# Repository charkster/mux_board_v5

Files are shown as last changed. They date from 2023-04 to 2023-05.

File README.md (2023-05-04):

# mux_board_v5
Custom PCB with SAMD21 QT PY controlling TWO ADG1606BRUZ 16 input muxes! This board is 30% smaller than V3 and uses a single 16x2 pin header. There are two firmwares for this board, as the backside input pin numbering does not match the topside numbering. You can select which side you would like to be on-top... the QT PY board is much taller than the ADG1606BRUZ packages, and I plan to have the backside on-top (to aviod any unwanted contact with the boards that I connect to).

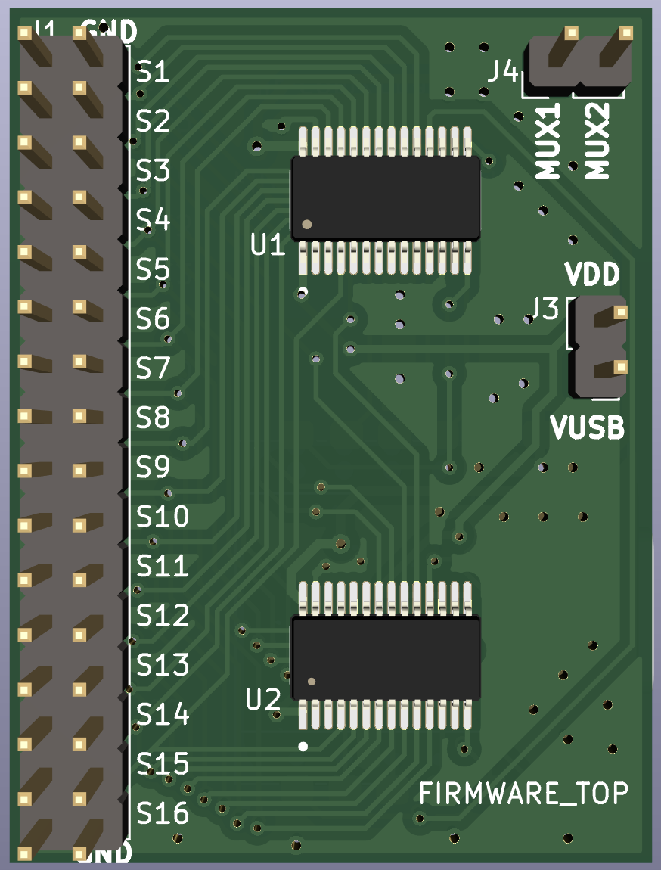
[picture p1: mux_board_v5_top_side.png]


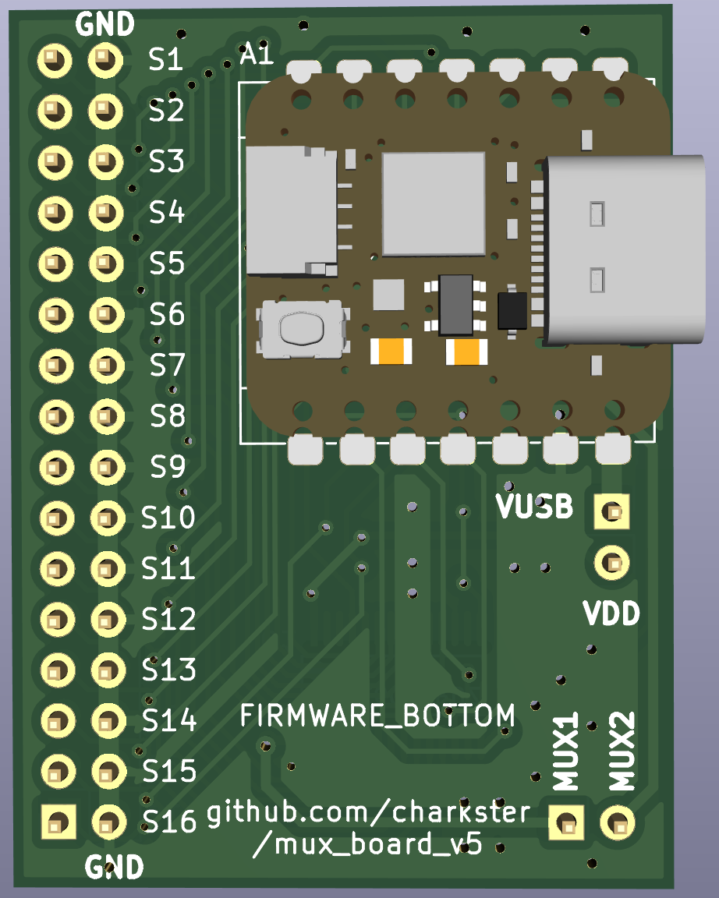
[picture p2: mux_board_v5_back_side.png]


Check-out my **PDF** [schematic](https://github.com/charkster/mux_board_v5/blob/main/mux_board_v5.pdf) !!

The SAMD21 QT PY can be programmed with the appropriate file (drag-n-drop) from the uf2_firmware folder. 

**Supported USBTMC commands:**

**MUX1:EN 1** # enable MUX1, a zero will disable the mux

**MUX1:SEL 1** # select S1 input, values 1 through 16 are valid

**MUX1:EN?** # this query returns the state of MUX1

**MUX1:SEL?** # this query returns the presently selected input

***RST** # disables all MUX enables

***IDN?** # returns valid commands and this URL

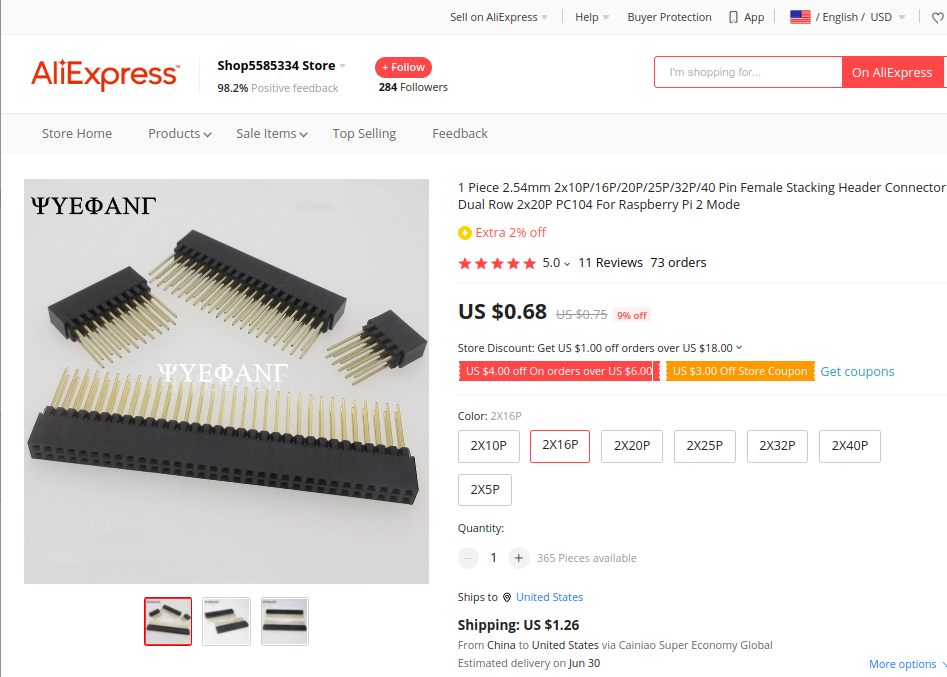
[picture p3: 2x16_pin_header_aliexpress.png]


2x16 2.54mm stacking headers can be found on [Aliexpress](https://www.aliexpress.us/item/2255800630914427.html)



SAMD21 QT PY and ADG1606BRUZ ICs can be found on Digikey/Mouser.

The tinyusb_usbtmc_src files are modifications of https://github.com/hathach/tinyusb source files.

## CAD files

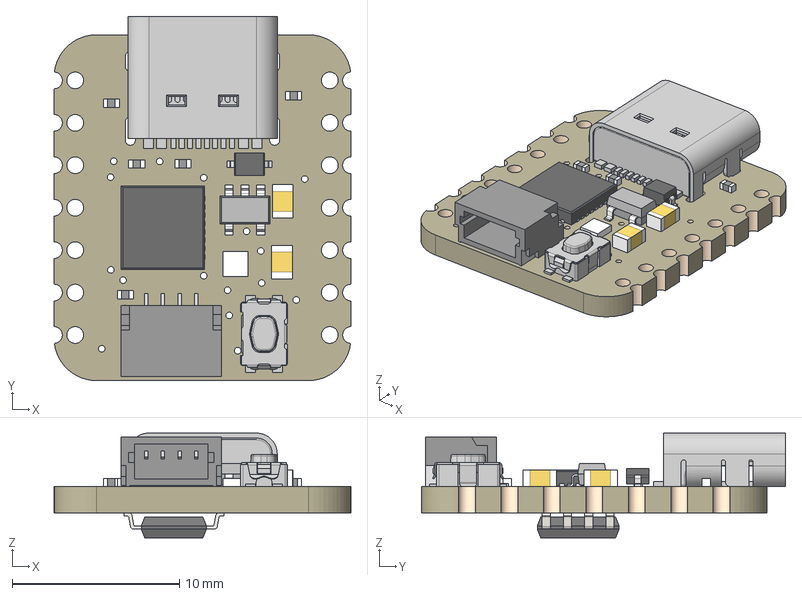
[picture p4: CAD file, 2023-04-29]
QTPY.step
17.8 x 21.8 x 6.28 mm
Board
10uF x 2
reset
ATSAMD21E
TPB1,27
5.1K x 5
USB TYPE C
STEMMA_I2C_QTSKINNY
AP2112K-3.3
WS2812B_SK6805_1515
NSR0320
SOIC8_150MIL

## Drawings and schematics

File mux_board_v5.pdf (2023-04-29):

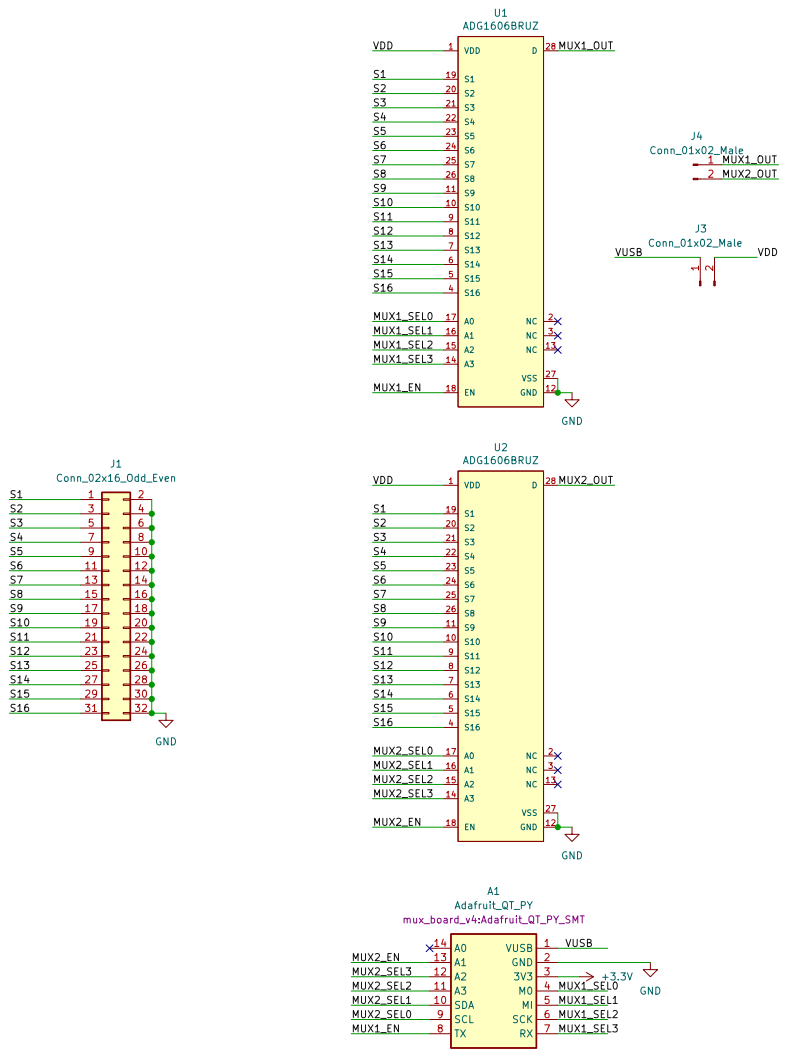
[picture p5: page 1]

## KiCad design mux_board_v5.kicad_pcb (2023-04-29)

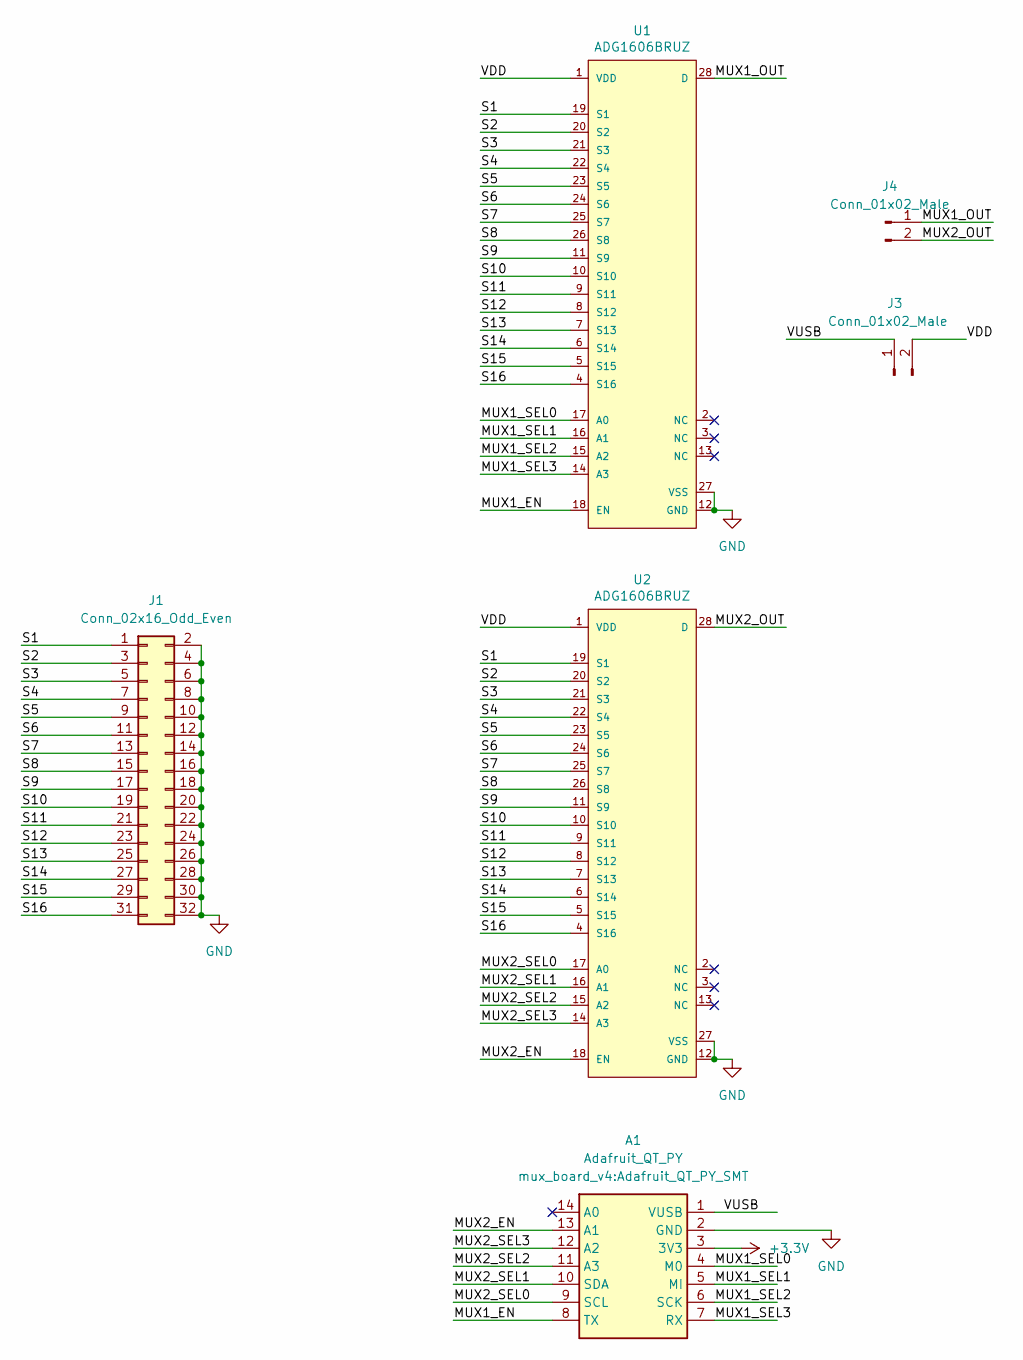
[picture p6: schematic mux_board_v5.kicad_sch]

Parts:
A1: Adafruit_QT_PY; Adafruit_QT_PY_SMT
J1: Conn_02x16_Odd_Even; PinHeader_2x16_P2.54mm_Vertical
J3, J4: Conn_01x02_Male; PinHeader_1x02_P2.54mm_Vertical
U1, U2: ADG1606BRUZ; Analog_Devices-RU-28-0-0-IPC_A; mouser part number 584-ADG1606BRUZ; digikey description IC MULTIPLEXER 1 X 16 28TSSOP

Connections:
+3V3: A1.3 (3V3)
/MUX1_EN: A1.8 (TX), U1.18 (EN)
/MUX1_OUT: J4.1, U1.28 (D)
/MUX1_SEL0: A1.4 (M0), U1.17 (A0)
/MUX1_SEL1: A1.5 (MI), U1.16 (A1)
/MUX1_SEL2: A1.6 (SCK), U1.15 (A2)
/MUX1_SEL3: A1.7 (RX), U1.14 (A3)
/MUX2_EN: A1.13 (A1), U2.18 (EN)
/MUX2_OUT: J4.2, U2.28 (D)
/MUX2_SEL0: A1.9 (SCL), U2.17 (A0)
/MUX2_SEL1: A1.10 (SDA), U2.16 (A1)
/MUX2_SEL2: A1.11 (A3), U2.15 (A2)
/MUX2_SEL3: A1.12 (A2), U2.14 (A3)
/S1: J1.1, U1.19 (S1), U2.19 (S1)
/S2: J1.3, U1.20 (S2), U2.20 (S2)
/S3: J1.5, U1.21 (S3), U2.21 (S3)
/S4: J1.7, U1.22 (S4), U2.22 (S4)
/S5: J1.9, U1.23 (S5), U2.23 (S5)
/S6: J1.11, U1.24 (S6), U2.24 (S6)
/S7: J1.13, U1.25 (S7), U2.25 (S7)
/S8: J1.15, U1.26 (S8), U2.26 (S8)
/S9: J1.17, U1.11 (S9), U2.11 (S9)
/S10: J1.19, U1.10 (S10), U2.10 (S10)
/S11: J1.21, U1.9 (S11), U2.9 (S11)
/S12: J1.23, U1.8 (S12), U2.8 (S12)
/S13: J1.25, U1.7 (S13), U2.7 (S13)
/S14: J1.27, U1.6 (S14), U2.6 (S14)
/S15: J1.29, U1.5 (S15), U2.5 (S15)
/S16: J1.31, U1.4 (S16), U2.4 (S16)
/VDD: J3.2, U1.1 (VDD), U2.1 (VDD)
/VUSB: A1.1 (VUSB), J3.1
GND: A1.2 (GND), J1.2, J1.4, J1.6, J1.8, J1.10, J1.12, J1.14, J1.16, J1.18, J1.20, J1.22, J1.24, J1.26, J1.28, J1.30, J1.32, U1.12 (GND), U1.27 (VSS), U2.12 (GND), U2.27 (VSS)

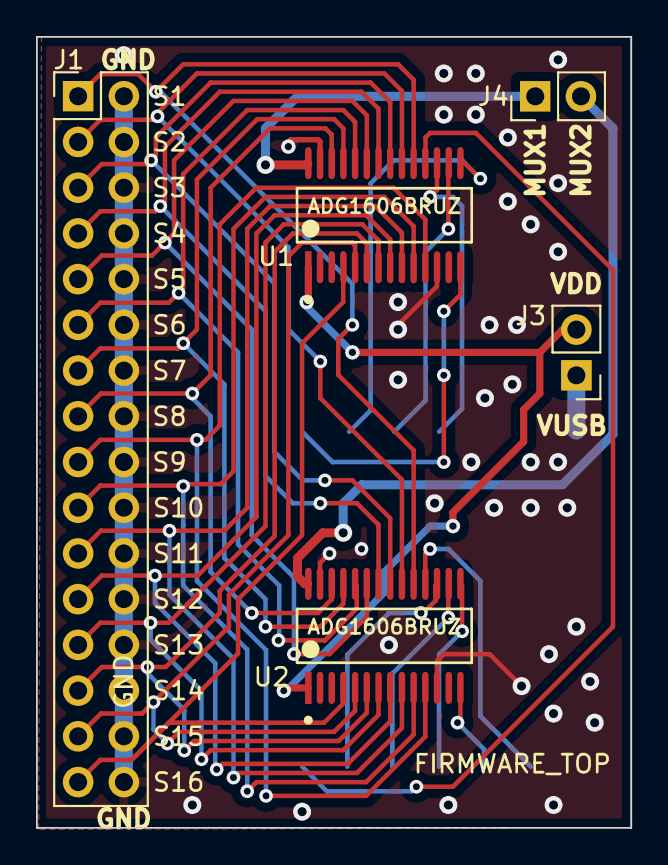
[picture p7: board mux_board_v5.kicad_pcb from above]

Board: 2 copper layers, 33.0 x 43.9 mm, 6 parts (1 on the bottom side), 31 nets.

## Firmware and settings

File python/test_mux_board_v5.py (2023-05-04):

import pyvisa
rm = pyvisa.ResourceManager('@py') # remove '@py' if running on Windows
print(rm.list_resources())
samd21 = rm.open_resource('USB0::51966::16384::123456::0::INSTR')
print(samd21.query("*IDN?"))
print(samd21.query("MUX1:SEL?"))
samd21.write("MUX1:SEL 16")
print(samd21.query("MUX1:SEL?"))
print(samd21.query("MUX1:EN?"))
samd21.write("MUX1:EN 1")
print(samd21.query("MUX1:EN?"))
print(samd21.query("MUX2:SEL?"))
samd21.write("MUX2:SEL 15")
print(samd21.query("MUX2:SEL?"))
print(samd21.query("MUX2:EN?"))
samd21.write("MUX2:EN 1")
print(samd21.query("MUX2:EN?"))
samd21.write("*RST")
print(samd21.query("MUX1:SEL?"))
print(samd21.query("MUX1:EN?"))
print(samd21.query("MUX2:SEL?"))
print(samd21.query("MUX2:EN?"))

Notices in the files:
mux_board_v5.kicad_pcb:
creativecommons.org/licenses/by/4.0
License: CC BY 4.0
